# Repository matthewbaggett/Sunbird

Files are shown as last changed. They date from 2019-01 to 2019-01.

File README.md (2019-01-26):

# Sunbird

Version: rev11.

## Technical information

This is a board designed around an off-the-shelf ESP8266 ESP-12(E|F|S) module.

### Component choices

 * [ESP8266](./docs/esp8266ex.pdf) single-core 160Mhz 32 bit microcontroller with Wifi, 32K RAM and 4MB ROM as main CPU.
 * 2x 5050 RGB notification LEDs on either side of the PCB at the rear end
 * USB C charge and programming port.
 * [CH340g](./docs/CH340DS1.pdf) USB UART controller, with automatic reset circuitry for programming CPU.
 * [FS312F-G](./docs/FS312F-G-DS-10_EN.pdf) (and associated double-mosfet) short circuit protection circuitry. This also provides overcharge/overdischarge protection
 * [TP4056](./docs/TP4056.pdf) li-ion battery charger circuit. CHRG and STDBY signals passed through to CPU.
 * [ADXL345](./docs/ADXL345.pdf) Accellerometer for smart-power-off and usage detection using i2c bus with interrupt line.
 * [FM116B](./docs/FM116B.pdf) motor driver H-bridge IC. Warning: Datasheet almost entirely in Chinese.
 * Integrated 500mA fuse on PCB.
 * Standardised around 0603 size components where possible.
 * [Tag-Connect TC2030 no-legs](http://www.tag-connect.com/TC2030-MCP-NL) zero-pcb-parts connector used for programming and debugging before the CH340G is brought up, and for diagnosis when the CH340G is not populated, or otherwise unavailable due to failure.

### Technical features

 * Ability to field-program in-situ using USB bus.
 * Ability to OTA (Over The Air) program device.
 * Ability to sample battery voltage without incurring passive current draw, using 2 high-resistence resistors and a single transitor to enable battery sampling.
 * Ability to run while charging battery.
 * Ability to show status using RGB colour LED on both sides of circuit board.

### Known issues
 * 3.3v regulator has been problematic so far. Hopefully resolved in rev11.
 * 5050 RGB LEDs don't have consistent pinout of which colour channel is on which pin, meaning the value of R8020-22 are unpredictable, and subject to change before assembly. I have debated using WS2812B or similar as a replacement, but increasing parts cost and program complexity deterred me.

### Licencing

Sunbird is licenced under the [Open Hardware TAPR licence](./LICENCE.md).

## PCB
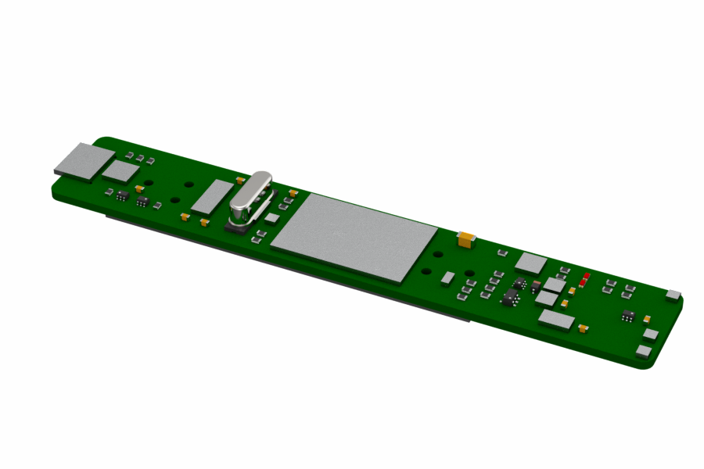
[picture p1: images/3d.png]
Render

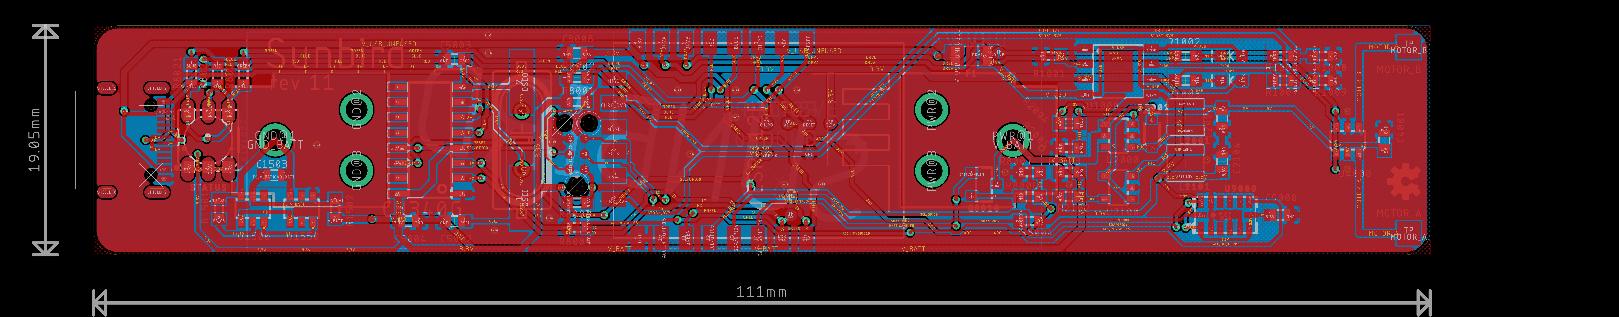
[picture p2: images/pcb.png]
PCB view


## Schematics

### Processor
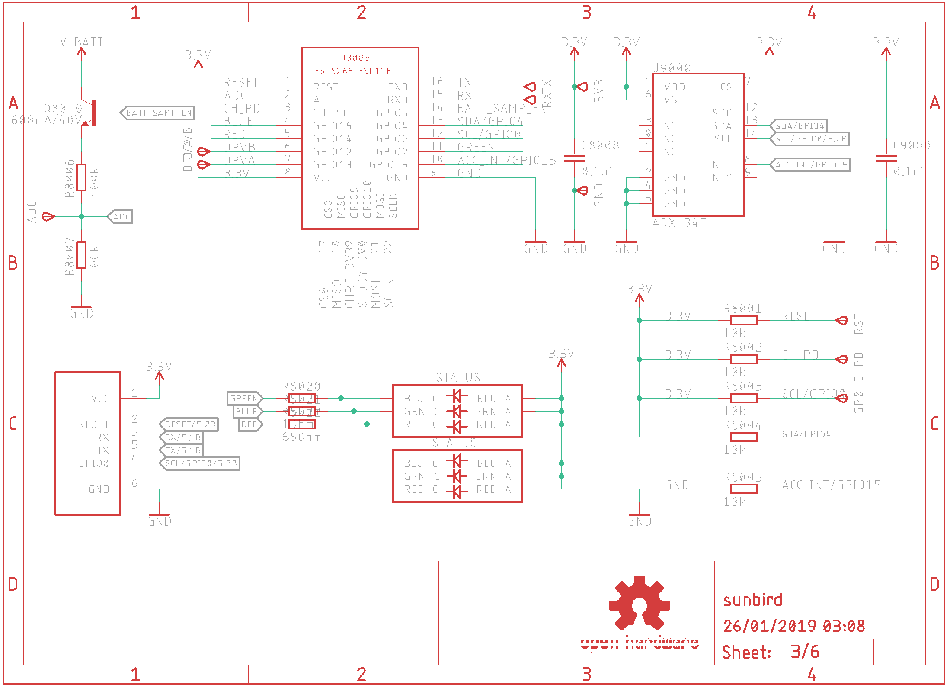
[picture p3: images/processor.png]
Processor


### Battery Charger Circuit
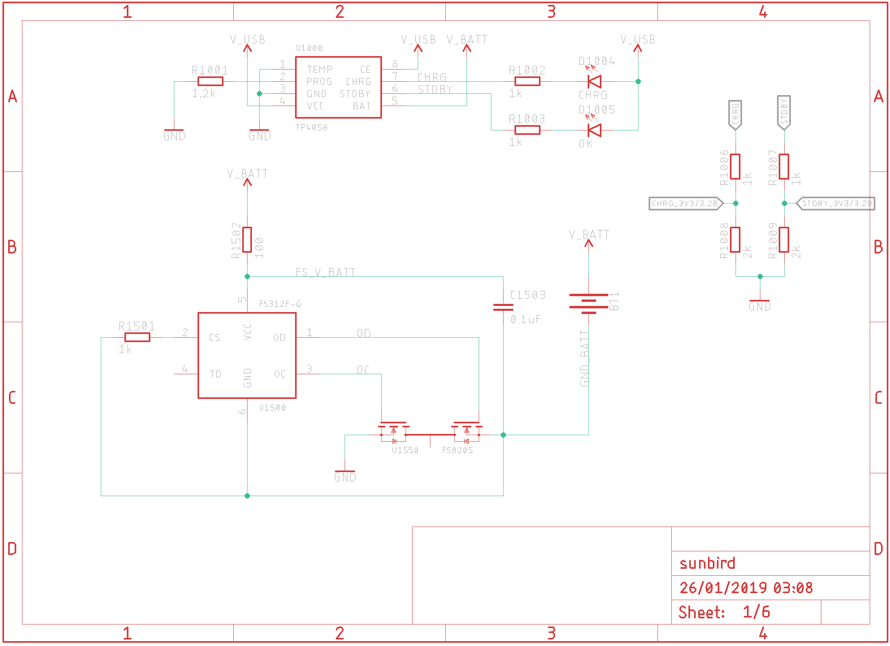
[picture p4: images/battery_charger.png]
Battery Charger


### Power Regulator
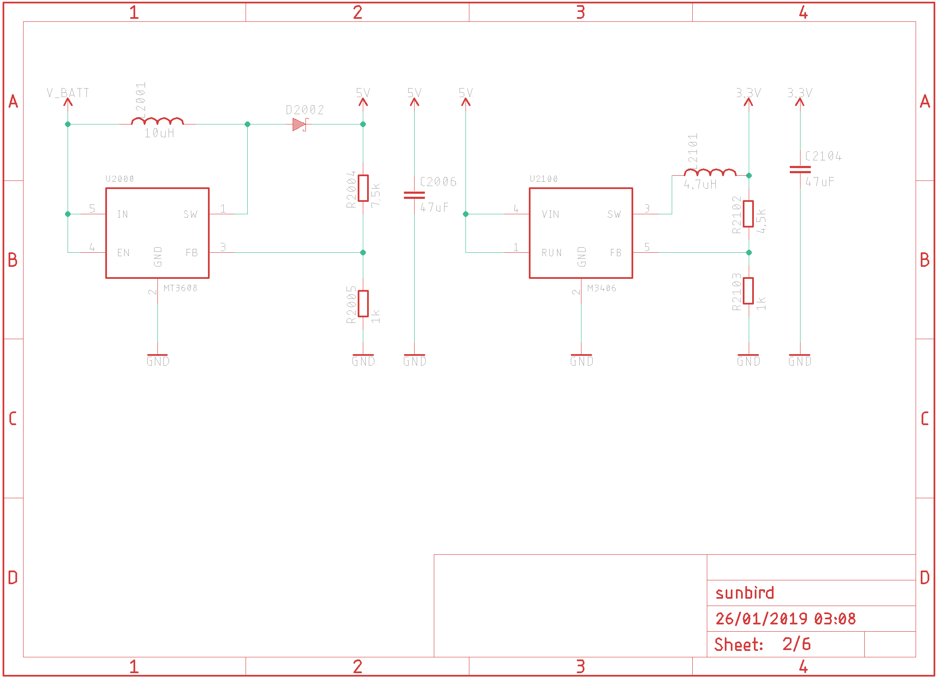
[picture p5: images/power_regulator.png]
Power Regulator


### Motor Driver
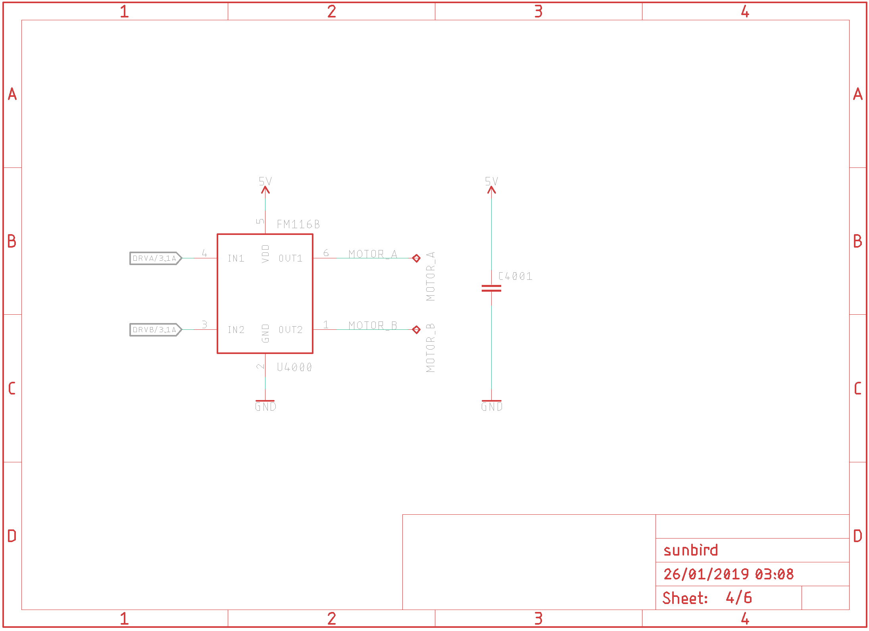
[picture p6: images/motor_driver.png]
Motor Driver


### USB UART
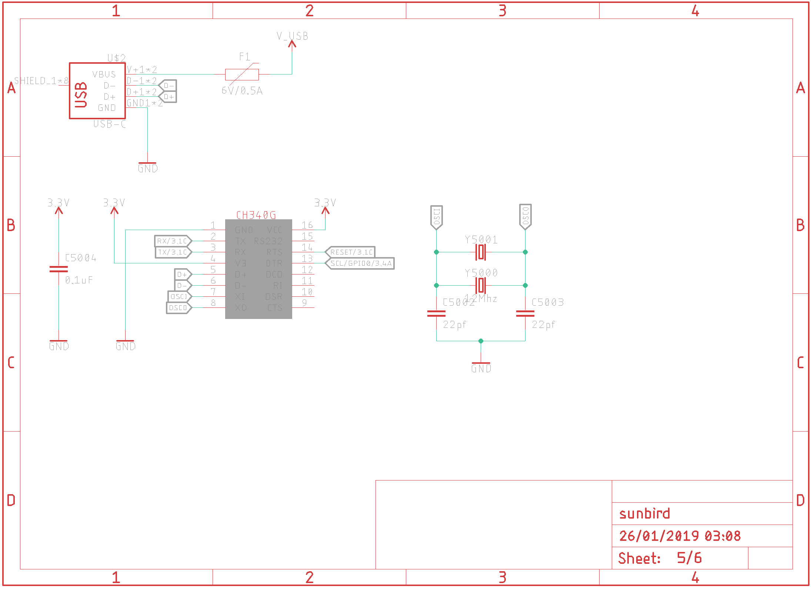
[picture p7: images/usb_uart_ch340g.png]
USB UART


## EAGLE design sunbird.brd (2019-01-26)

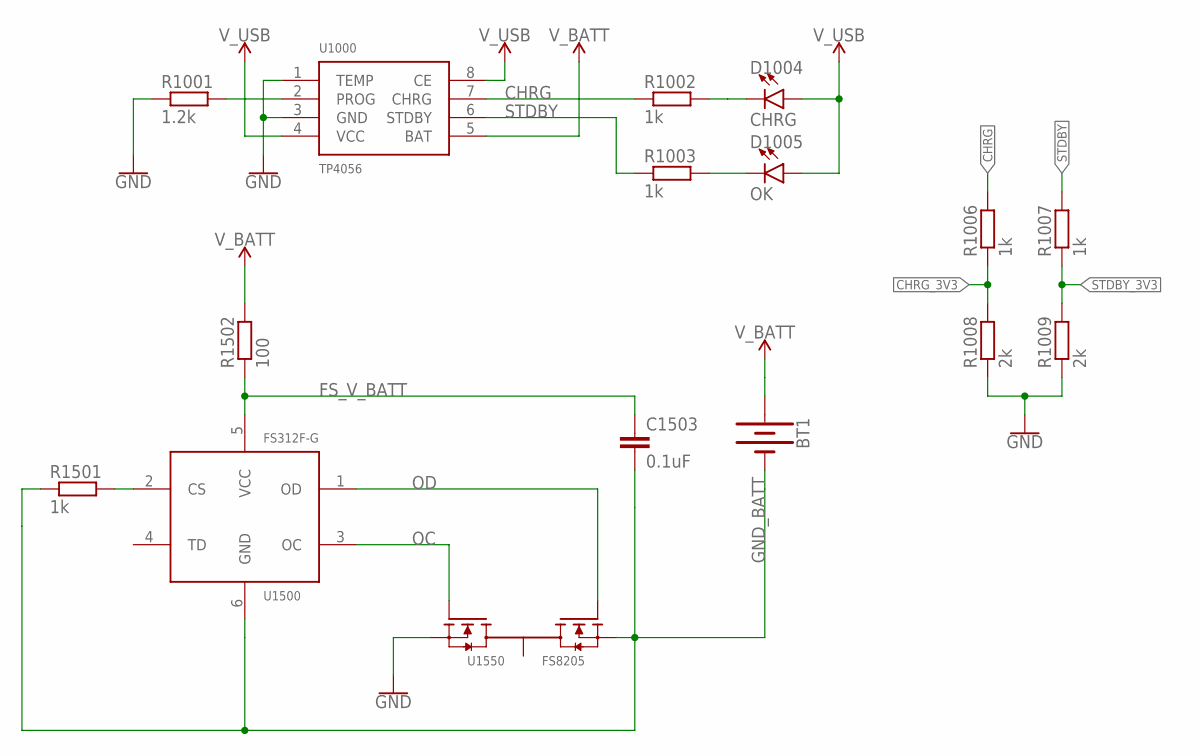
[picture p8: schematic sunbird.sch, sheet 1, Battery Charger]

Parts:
BT1: BATTERY-18650; BATTERY_18650-HOLDER
C1503: 0.1uF; C0603
D1004: CHRG; LED-0603
D1005: OK; LED-0603
R1001: 1.2k; R0603
R1002, R1003, R1006, R1007, R1501: 1k; R0603
R1008, R1009: 2k; R0603
R1502: 100; R0603
U1000: TP4056; SOP-8-THERMAL
U1500: FS312F-G; SOT23-6
U1550: FS8205; SOT23-6

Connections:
CHRG: R1002.1, R1006.2, U1000.7 (CHRG)
CHRG_3V3: R1006.1, R1008.2; also elsewhere on the board
FS_CS: R1501.2, U1500.2 (CS)
FS_V_BATT: C1503.1, R1502.1, U1500.5 (VCC)
GND: R1001.1, R1008.1, R1009.1, U1000.1 (TEMP), U1000.3 (GND), U1550.1 (S1); also elsewhere on the board
GND_BATT: BT1.GND@1 (-), C1503.2, R1501.1, U1500.6 (GND), U1550.3 (S2)
unnamed: R1001.2, U1000.2 (PROG)
unnamed: D1005.C, R1003.2
unnamed: D1004.C, R1002.2
OC: U1500.3 (OC), U1550.6 (G1)
OD: U1500.1 (OD), U1550.4 (G2)
STDBY: R1003.1, R1007.2, U1000.6 (STDBY)
STDBY_3V3: R1007.1, R1009.2; also elsewhere on the board
V_BATT: BT1.PWR@1 (+), R1502.2, U1000.5 (BAT); also elsewhere on the board
V_USB: D1004.A, D1005.A, U1000.4 (VCC), U1000.8 (CE); also elsewhere on the board

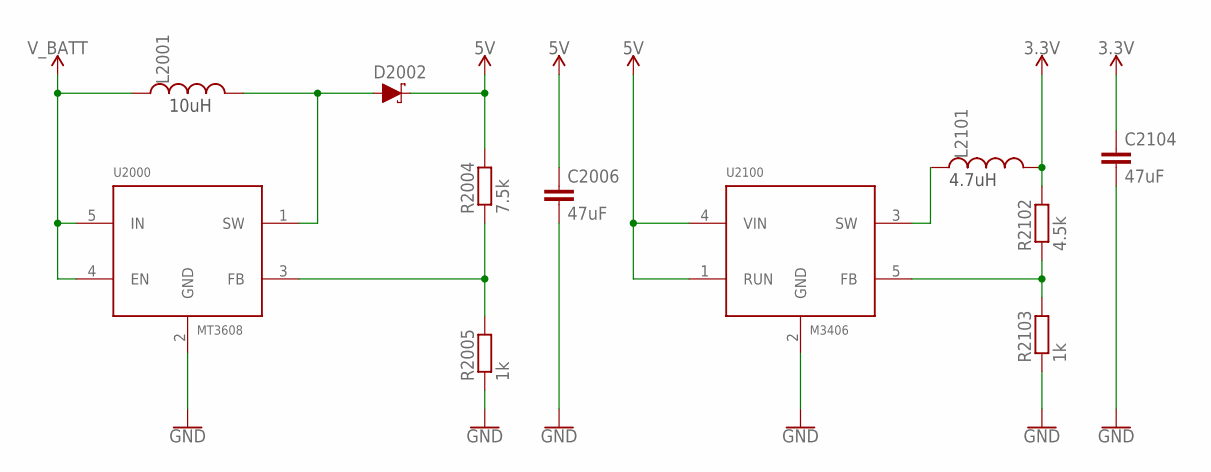
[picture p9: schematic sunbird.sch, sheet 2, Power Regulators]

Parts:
C2006, C2104: 47uF; C0603
D2002: DIODE-SCHOTTKY-PMEG4005EJ; SOD-323
L2001: 10uH; INDUCTOR_3.0X3.0
L2101: 4.7uH; INDUCTOR_3.0X3.0
R2004: 7.5k; R0603
R2005, R2103: 1k; R0603
R2102: 4.5k; R0603
U2000: MT3608; SOT23-6
U2100: M3406; SOT23-5

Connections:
3.3V: C2104.1, L2101.P$2 (2), R2102.2; also elsewhere on the board
5V: C2006.1, D2002.C, R2004.2, U2100.1 (RUN), U2100.4 (VIN); also elsewhere on the board
BUCK: D2002.A, L2001.P$2 (2), U2000.1 (SW)
GND: C2006.2, C2104.2, R2005.1, R2103.1, U2000.2 (GND), U2100.2 (GND); also elsewhere on the board
unnamed: L2101.P$1 (1), U2100.3 (SW)
unnamed: R2102.1, R2103.2, U2100.5 (FB)
unnamed: R2004.1, R2005.2, U2000.3 (FB)
V_BATT: L2001.P$1 (1), U2000.4 (EN), U2000.5 (IN); also elsewhere on the board

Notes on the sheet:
10uH
4.7uH

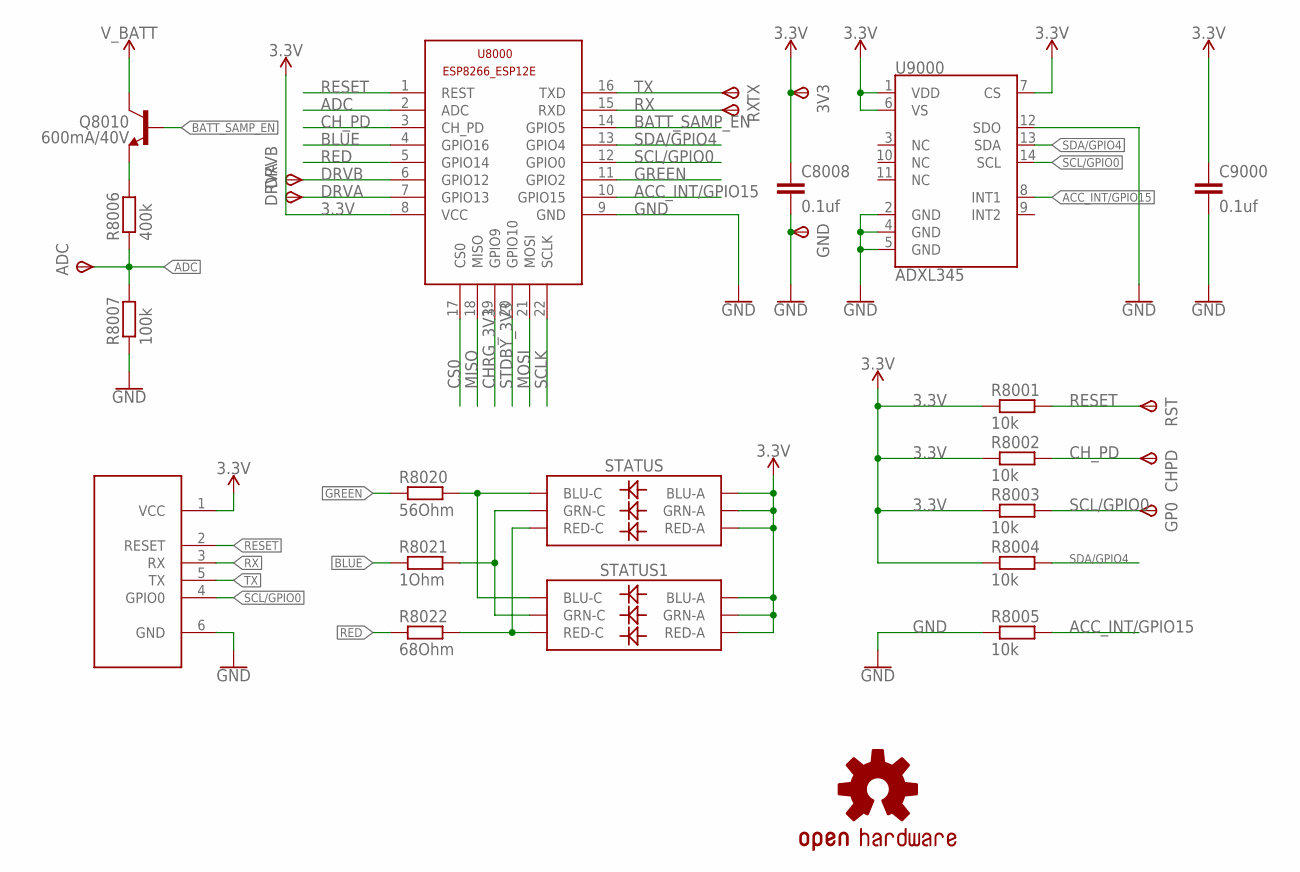
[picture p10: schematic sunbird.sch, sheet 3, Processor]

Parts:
3V3: TPSTP10R; TP10R
ADC: TPSTP10R; TP10R
C8008, C9000: 0.1uf; C0603
CHPD: TPSTP10R; TP10R
DEBUG: ESP8266_PROGRAMMER; TC2030-IDC-NL
DRVA: TPSTP10R; TP10R
DRVB: TPSTP10R; TP10R
GND: TPSTP10R; TP10R
GP0: TPSTP10R; TP10R
LOGO1: OSHW-LOGOS; OSHW-LOGO-S
Q8010: 600mA/40V; SOT23-3
R8001, R8002, R8003, R8004, R8005: 10k; R0603
R8006: 400k; R0603
R8007: 100k; R0603
R8020: 56Ohm; R0603
R8021: 1Ohm; R0603
R8022: 68Ohm; R0603
RST: TPSTP10R; TP10R
RX: TPSTP10R; TP10R
STATUS, STATUS1: LED-RGBNO_IC; LED-TRICOLOR-5050
TX: TPSTP10R; TP10R
U8000: ESP8266-12EESP8266-ESP12E; ESP8266-ESP12E
U9000: ADXL345; LGA-14

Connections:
3.3V: 3V3.TP, C8008.1, C9000.1, DEBUG.1 (VCC), R8001.1, R8002.1, R8003.1, R8004.1, STATUS.1 (GRN-A), STATUS.2 (RED-A), STATUS.3 (BLU-A), STATUS1.1 (GRN-A), STATUS1.2 (RED-A), STATUS1.3 (BLU-A), U8000.8 (VCC), U9000.1 (VDD), U9000.6 (VS), U9000.7 (CS); also elsewhere on the board
ACC_INT/GPIO15: R8005.2, U8000.10 (GPIO15), U9000.8 (INT1)
ADC: ADC.TP, R8006.1, R8007.2, U8000.2 (ADC)
BATT_SAMP_EN: Q8010.1 (B), U8000.14 (GPIO5)
BLUE: R8021.1, U8000.4 (GPIO16)
CHRG_3V3: U8000.19 (GPIO9); also elsewhere on the board
CH_PD: CHPD.TP, R8002.2, U8000.3 (CH_PD)
CS0: U8000.17 (CS0)
DRVA: DRVA.TP, U8000.7 (GPIO13); also elsewhere on the board
DRVB: DRVB.TP, U8000.6 (GPIO12); also elsewhere on the board
GND: C8008.2, C9000.2, DEBUG.6 (GND), GND.TP, R8005.1, R8007.1, U8000.9 (GND), U9000.2 (GND), U9000.4 (GND), U9000.5 (GND), U9000.12 (SDO); also elsewhere on the board
GREEN: R8020.1, U8000.11 (GPIO2)
MISO: U8000.18 (MISO)
MOSI: U8000.21 (MOSI)
unnamed: Q8010.2 (E), R8006.2
unnamed: R8020.2, STATUS.4 (BLU-C), STATUS1.4 (BLU-C)
unnamed: R8021.2, STATUS.6 (GRN-C), STATUS1.6 (GRN-C)
unnamed: R8022.2, STATUS.5 (RED-C), STATUS1.5 (RED-C)
RED: R8022.1, U8000.5 (GPIO14)
RESET: DEBUG.2 (RESET), R8001.2, RST.TP, U8000.1 (REST); also elsewhere on the board
RX: DEBUG.3 (RX), RX.TP, U8000.15 (RXD); also elsewhere on the board
SCL/GPIO0: DEBUG.4 (GPIO0), GP0.TP, R8003.2, U8000.12 (GPIO0), U9000.14 (SCL); also elsewhere on the board
SCLK: U8000.22 (SCLK)
SDA/GPIO4: R8004.2, U8000.13 (GPIO4), U9000.13 (SDA)
STDBY_3V3: U8000.20 (GPIO10); also elsewhere on the board
TX: DEBUG.5 (TX), TX.TP, U8000.16 (TXD); also elsewhere on the board
V_BATT: Q8010.3 (C); also elsewhere on the board

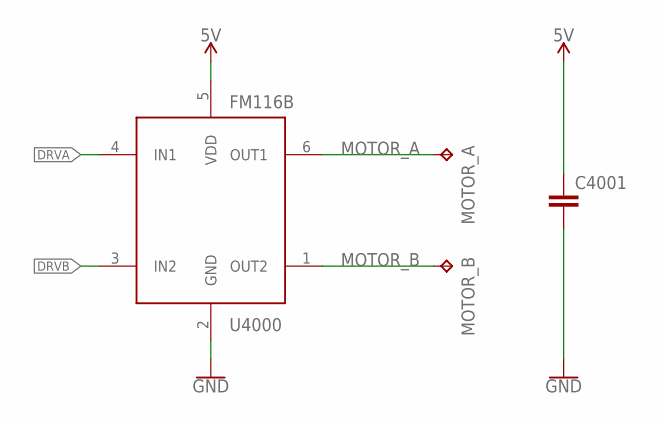
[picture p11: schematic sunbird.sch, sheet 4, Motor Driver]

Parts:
C4001: C-EUC0603; C0603
MOTOR_A: TPTP20SQ; TP20SQ
MOTOR_B: TPTP20SQ; TP20SQ
U4000: FM116B; SOT23-6

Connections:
5V: C4001.1, U4000.5 (VDD); also elsewhere on the board
DRVA: U4000.4 (IN1); also elsewhere on the board
DRVB: U4000.3 (IN2); also elsewhere on the board
GND: C4001.2, U4000.2 (GND); also elsewhere on the board
MOTOR_A: MOTOR_A.TP, U4000.6 (OUT1)
MOTOR_B: MOTOR_B.TP, U4000.1 (OUT2)

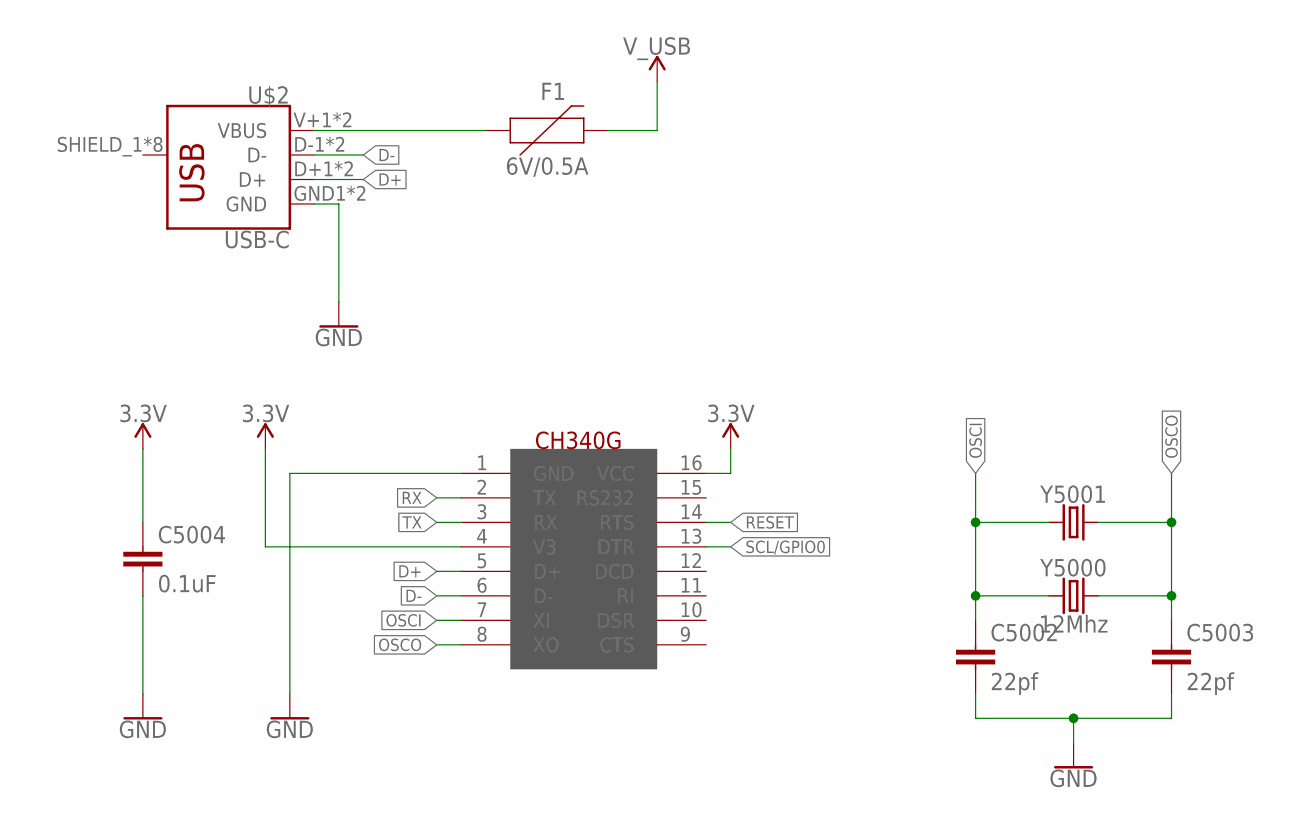
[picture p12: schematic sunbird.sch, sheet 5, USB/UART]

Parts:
C5002, C5003: 22pf; C0603
C5004: 0.1uF; C0603
F1: 6V/0.5A; 1206
U5000: CH340G; SOIC16
U$2: USB-C; USB_C-XKBENTERPRISEU262-16XN-4BVC11
Y5000: 12Mhz; HC49UP
Y5001: CRYSTALPTH-HC49UV; HC49U

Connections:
3.3V: C5004.1, U5000.4 (V3), U5000.16 (VCC); also elsewhere on the board
D+: U5000.5 (D+), U$2.D+1 (D+), U$2.D+2 (D+)
D-: U5000.6 (D-), U$2.D-1 (D-), U$2.D-2 (D-)
GND: C5002.2, C5003.2, C5004.2, U5000.1 (GND), U$2.GND1 (GND), U$2.GND2 (GND); also elsewhere on the board
OSCI: C5002.1, U5000.7 (XI), Y5000.1, Y5001.1
OSCO: C5003.1, U5000.8 (XO), Y5000.2, Y5001.2
RESET: U5000.14 (RTS); also elsewhere on the board
RX: U5000.2 (TX); also elsewhere on the board
SCL/GPIO0: U5000.13 (DTR); also elsewhere on the board
TX: U5000.3 (RX); also elsewhere on the board
V_USB: F1.2; also elsewhere on the board
V_USB_UNFUSED: F1.1, U$2.V+1 (VBUS), U$2.V+2 (VBUS)

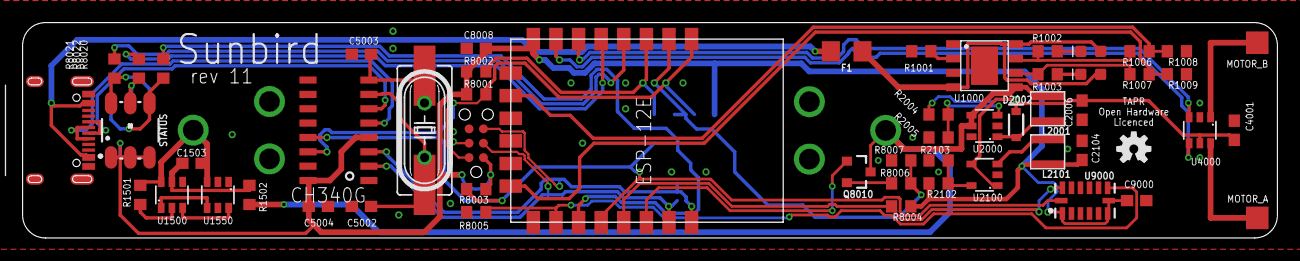
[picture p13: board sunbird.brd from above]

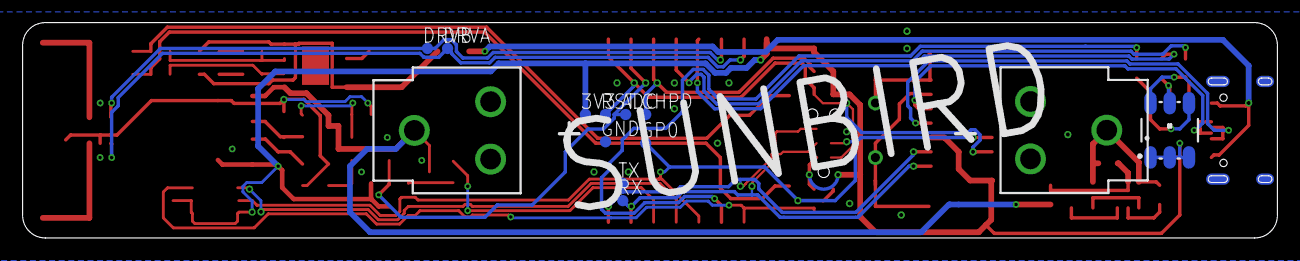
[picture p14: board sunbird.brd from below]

Board: 2 copper layers, 111.0 x 19.1 mm, 68 parts (12 on the bottom side), 46 nets.

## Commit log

2018-08-14 Initial schematics
    [sunbird.brd, sunbird.sch]
2018-08-14 Getting there
    [sunbird.brd, sunbird.sch]
2018-08-14 Almost done
    [sunbird.brd, sunbird.sch]
2018-08-16 Sunbird. Again.
    [sunbird.brd, sunbird.sch]
2018-08-16 Rotated the logo just a bit
    [sunbird.brd]
2018-08-16 Add a status LED
    [sunbird.brd, sunbird.sch]
2018-08-16 Renumber status resistors, reposition labels
    [sunbird.brd, sunbird.sch]
2018-08-16 Remove uneeded labels
    [sunbird.brd]
2018-08-16 Change LED signal names for clarity.
    [sunbird.brd, sunbird.sch]
2018-08-16 More beautification
    [sunbird.brd]
2018-08-16 Move logo to rear, bigger
    [sunbird.brd]
2018-08-16 Move logo to rear, bigger and more center-er
    [sunbird.brd]
2018-08-16 Board ordered
2018-08-16 yeah, lets keep zipped gerbers
2018-09-15 Revise the mess I made of the power regulators, add accellerometer. Motor now has a beefier 5v rail.
    [sunbird.brd, sunbird.sch]
2018-09-17 Missed changes
    [falcoln.brd, falcoln.sch]
2018-10-11 Adding image exports
    [sunbird.brd]
2018-10-28 Missed commits
    [sunbird-solderpaste_top.gbr]
2018-12-26 Changing ssd1306 lib... unbuggered some output.. unbuggered timers.. unbuggered debug a bit
2018-12-26 Debug packets now being sent - but the printf'd data is bad.
2018-12-26 Working i2c oled display - runs a test loop
2019-01-25 Revise PCB to use inductors + 47uF 0603 "miracle" caps from LCSC.
    [sunbird.brd, sunbird.sch]
2019-01-25 Remove Falcoln related stuff
    [falcoln.brd, falcoln.sch]
2019-01-25 Removing sensor array
    [sunbird.brd, sunbird.sch]
2019-01-25 Get rid of solderpaste gerber
    [sunbird-solderpaste_top.gbr]
2019-01-25 Rejig layout, add measurement indexes
    [sunbird.brd, sunbird.sch]
2019-01-26 Futzing around with via placement
    [sunbird.brd]
2019-01-26 Added USB-C socket. Put a copy of the RGB LED on the rear side. Rejigged components.
    [sunbird.brd, sunbird.sch]
2019-01-26 Add TAPR licence text to PCB silk
    [sunbird.brd]

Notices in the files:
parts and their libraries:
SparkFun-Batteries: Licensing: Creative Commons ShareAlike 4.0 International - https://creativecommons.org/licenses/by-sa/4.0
